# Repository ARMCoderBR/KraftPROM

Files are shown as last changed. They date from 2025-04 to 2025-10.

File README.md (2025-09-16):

## Project

EEPROM Programmer

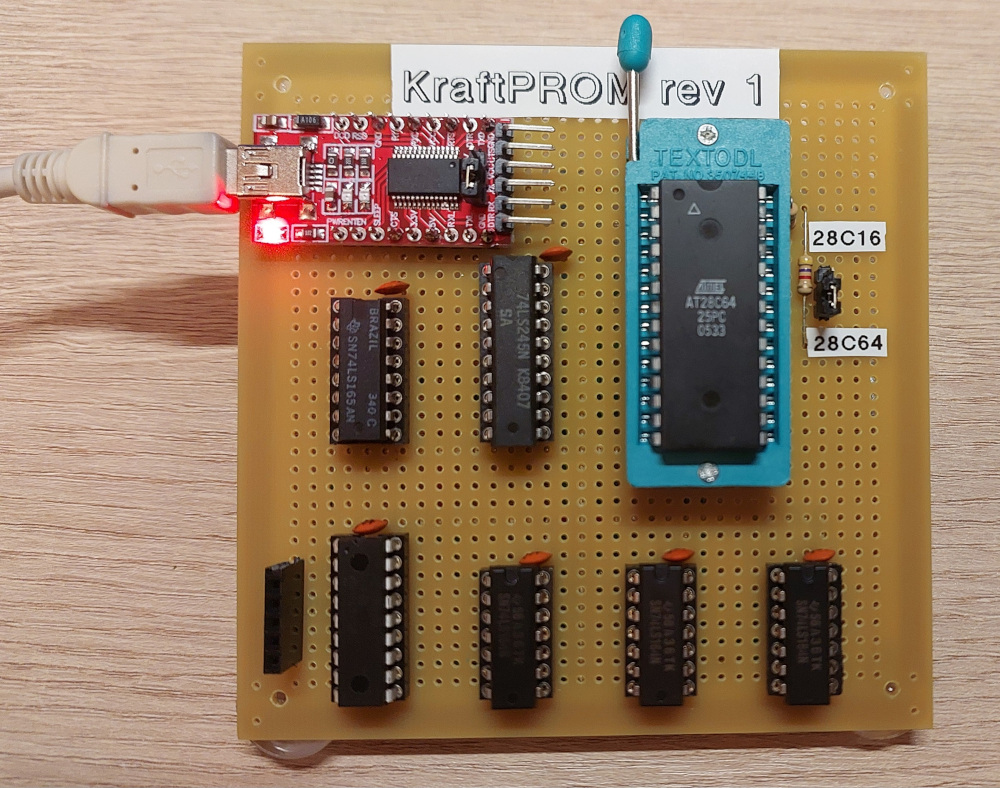
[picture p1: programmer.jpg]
EEPROM Programmer


## Description

A Hardware + Software suite to program EEPROMs (28C16 and 28C64).

## Version & Date
1.0 - 2025-APR-24

## Author
Milton Maldonado Jr (ARM_Coder)

## License
GPL V2

## Target

PC Client Software: Any Linux with GCC

The repo for the PC client is here: https://github.com/ARMCoderBR/eeprom_sender

Firmware: Microchip PIC16F628A under MPLABX IDE 6.X and XC8 2.X (no PRO License
          needed). A suitable HEX file is already supplied for this PIC, so no
          IDE and compiler will be needed unless you will choose to use a
          different PIC.

## Hardware Materials
```
1  x  Universal PCB or Breadboard
1  x  PIC16F628A
3  x  74LS164 or HC164
1  x  74LS245 or HC245
1  x  74LS165 or HC165
1  x  ZIF Socket DIP 28 PIN
7  x  Ceramic Cap 100nF
2  x  Resistor 4k7
1  x  Jumper 3 pin
1  x  Molex 5 pin female
3  x  DIP 14 Socket (not needed for breadboard)
1  x  DIP 16 Socket   "     "    "      "
1  x  DIP 18 Socket   "     "    "      "
1  x  DIP 20 Socket   "     "    "      "
1  x  PC Serial-to-TTL adapter with 5V compatibility
1+ x  28C16 or 28C64 as target(s)

Wires, solder, etc.
```

See picture and schematics.

NOTE: 

## Equipment needed to Build and Program

PC
USB cables
Solder
Cutter and pliers
Multimeter
PIC programmer dongle (eg Pickit3)

## Building the Programmer

As said, if you have the recommended PIC16F628A, you can program it with the
supplied HEX file. This is the easiest way because you don't need to install
the complete MPLABX and the C compiler.

**You will still need a PIC programming tool, that most likely you won't have.
Since programming this PIC is a once in a lifetime event, you'd better borrow
the programmer from a friend or use the company's programmer when no one is looking...**

The rest of the build is a no-brainer, just be careful with the connections.
The Serial-to-TTL adapter is very practical, it supplies the power to the
hardware (5VDC) and the communication signals (TX/RX/CTS).

## Using the Programmer

All the control is done by the PC client software, as indicated above.

## Disclaimer

This project is supplied 'as is' with no warranty against bugs and errors.

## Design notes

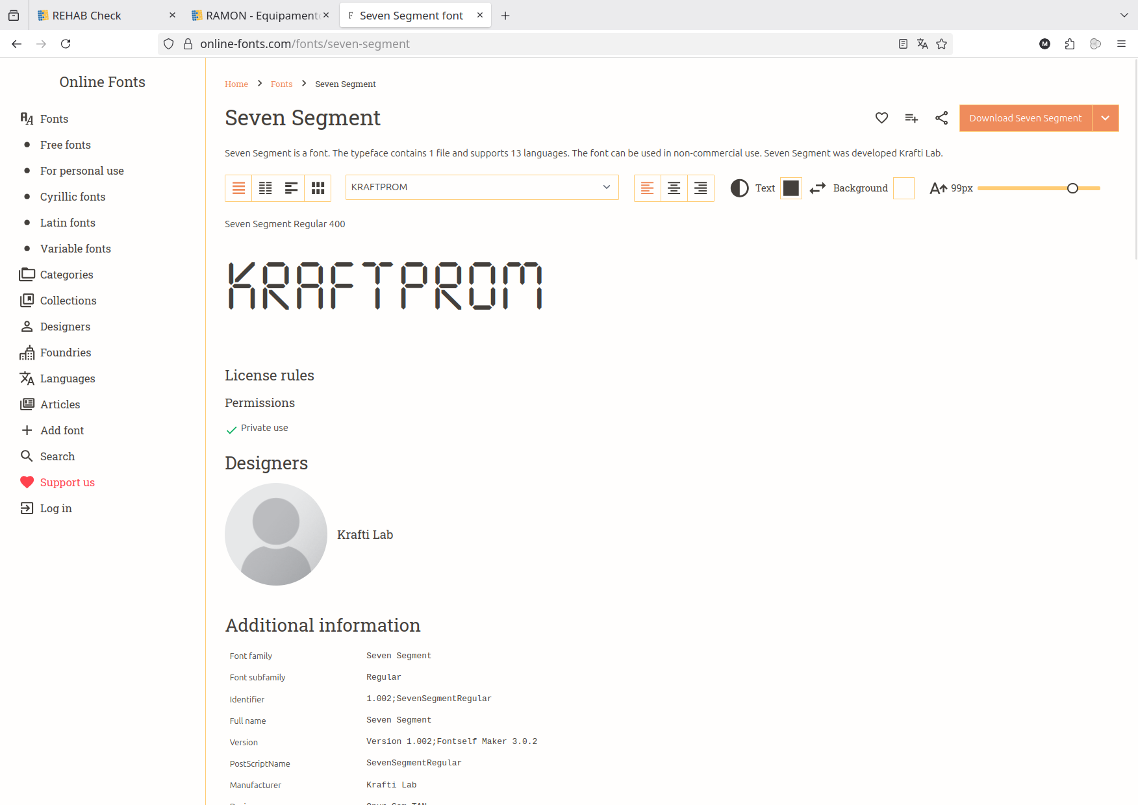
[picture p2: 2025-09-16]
Captura de tela_2025-09-16_14-19-43.png

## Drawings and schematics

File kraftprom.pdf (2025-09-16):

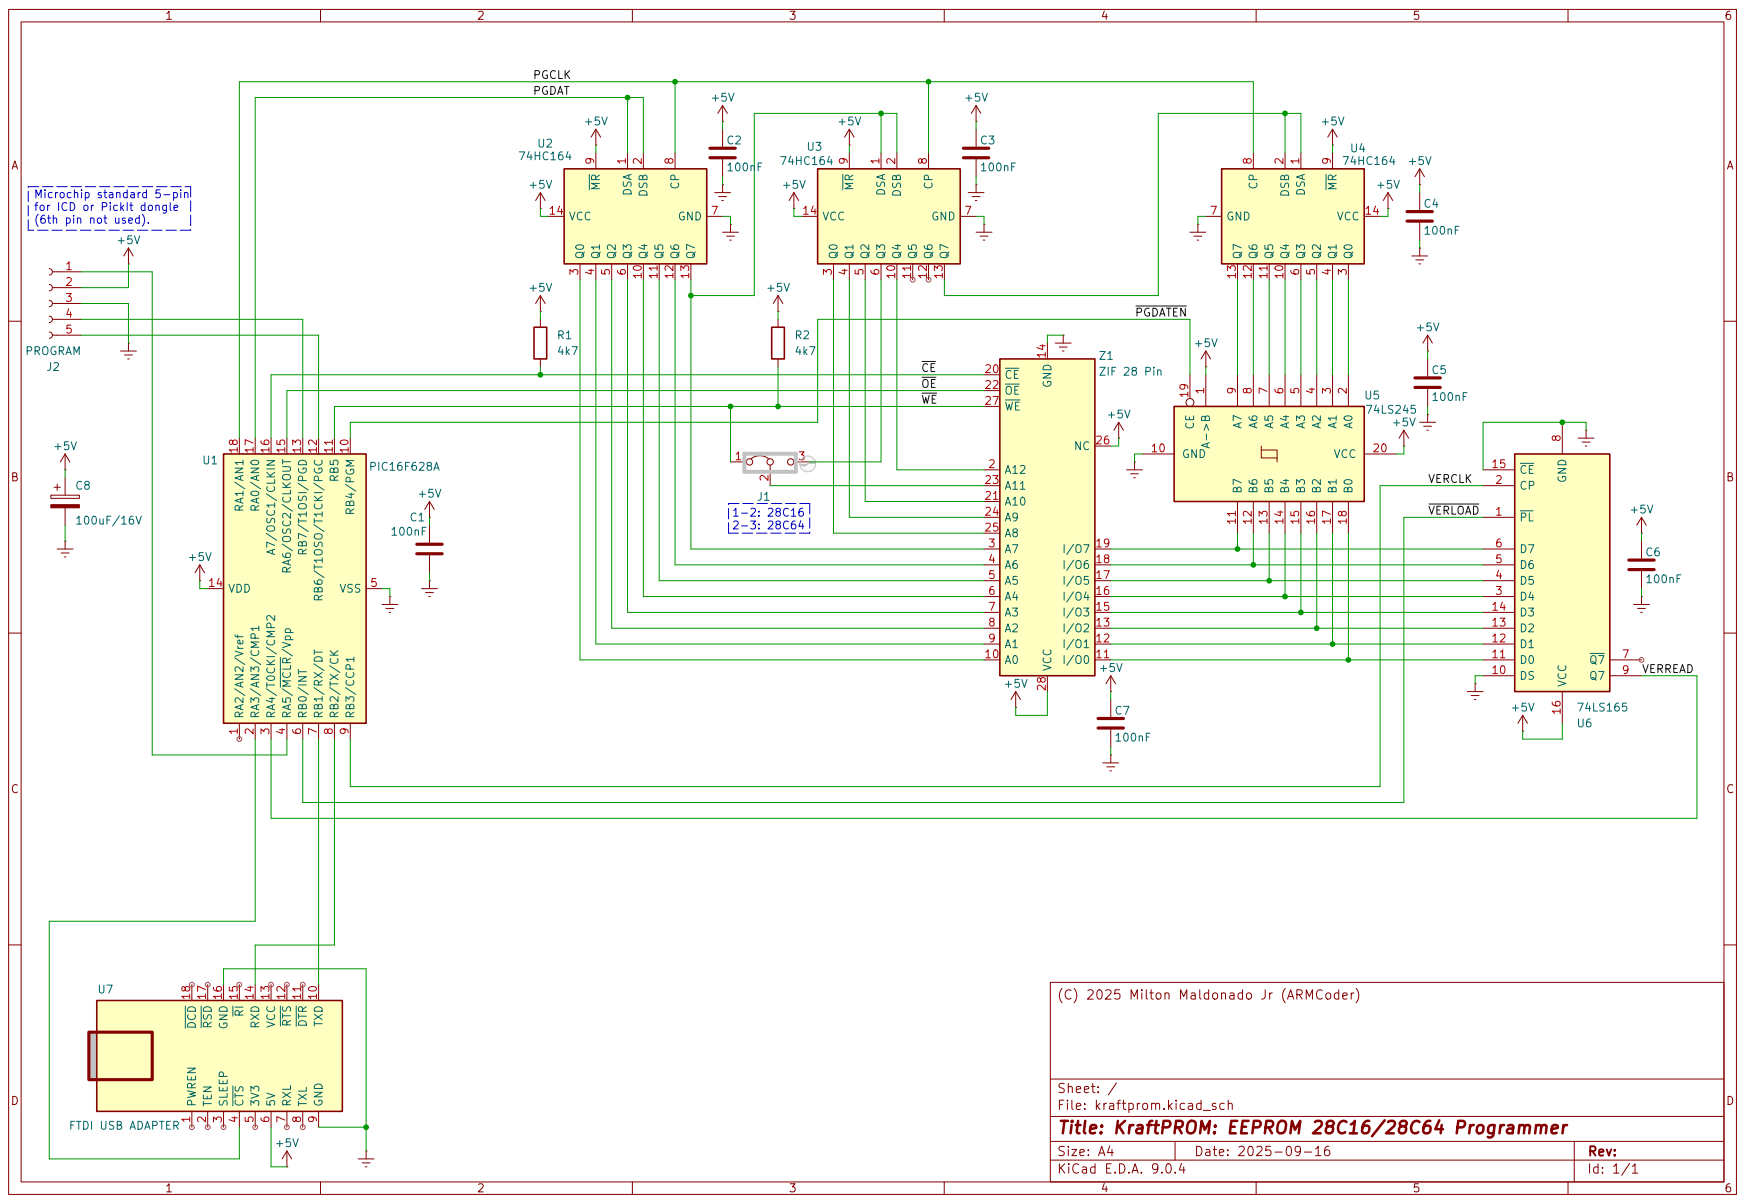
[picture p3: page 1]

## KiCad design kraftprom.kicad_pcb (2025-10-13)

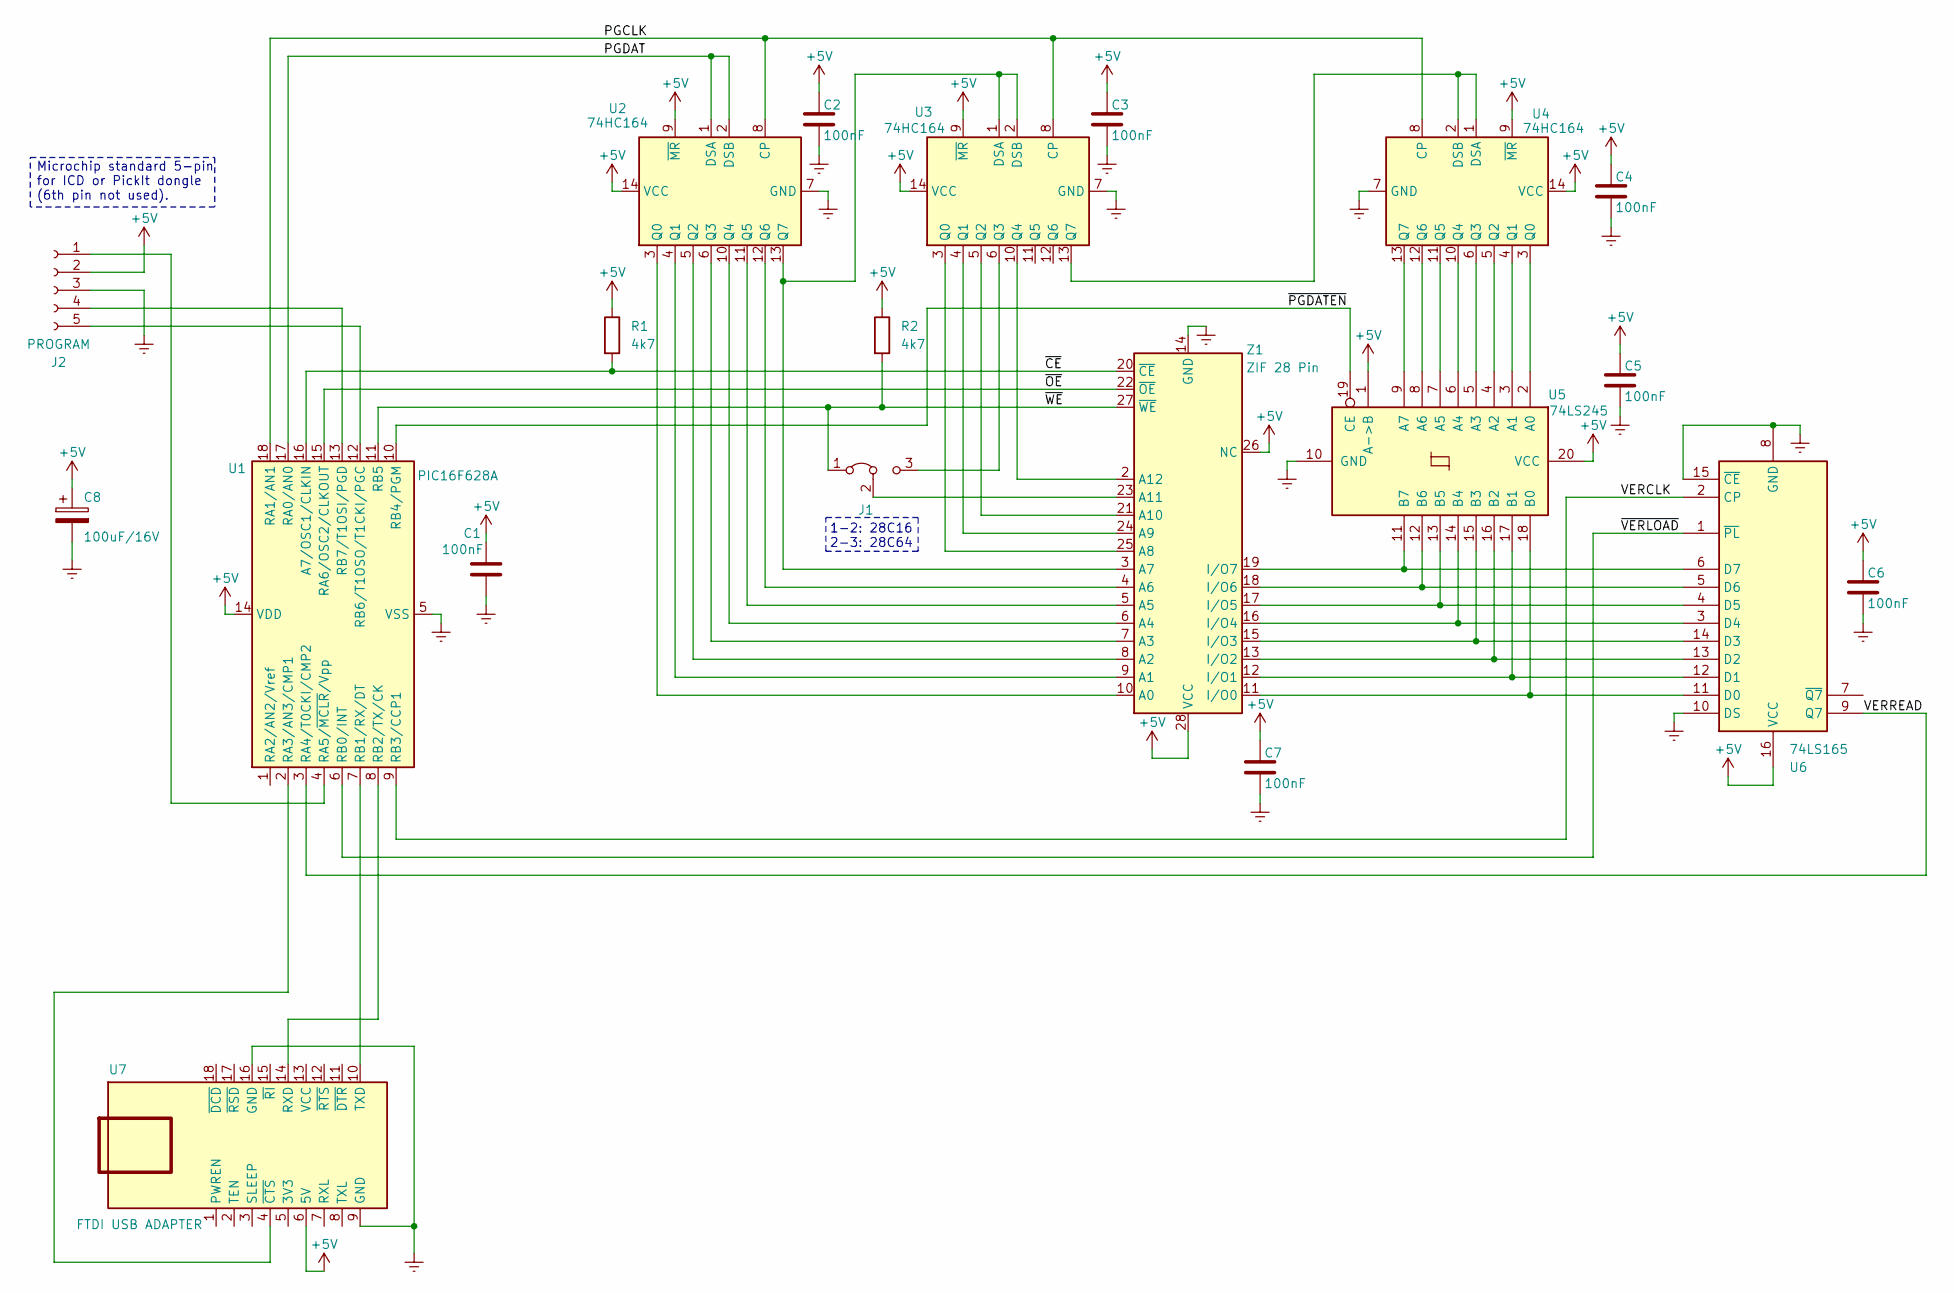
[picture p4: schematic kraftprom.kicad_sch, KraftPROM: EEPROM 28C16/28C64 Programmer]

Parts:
C1, C2, C3, C4, C5, C6, C7: 100nF
C8: 100uF/16V
J1: Jumper_3_Bridged12
J2: PROGRAM
R1, R2: 4k7
U1: PIC16F628A
U2, U3, U4: 74HC164
U5: 74LS245
U6: 74LS165
U7: FTDI USB ADAPTER
Z1: ZIF 28 Pin

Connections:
+5V: C1.1, C2.1, C3.1, C4.1, C5.1, C6.1, C7.1, C8.1, J2.2, R1.1, R2.1, U1.14 (VDD), U2.9 (~MR), U2.14 (VCC), U3.9 (~MR), U3.14 (VCC), U4.9 (~MR), U4.14 (VCC), U5.1 (A->B), U5.20 (VCC), U6.16 (VCC), U7.6 (5V), Z1.26 (NC), Z1.28 (VCC)
/PGCLK: U1.18 (RA1/AN1), U2.8 (CP), U3.8 (CP), U4.8 (CP)
/PGDAT: U1.17 (RA0/AN0), U2.1 (DSA), U2.2 (DSB)
/VERCLK: U1.9 (RB3/CCP1), U6.2 (CP)
/VERREAD: U1.3 (RA4/T0CKI/CMP2), U6.9 (Q7)
/~CE: R1.2, U1.16 (A7/OSC1/CLKIN), Z1.20 (~CE)
/~OE: U1.15 (RA6/OSC2/CLKOUT), Z1.22 (~OE)
/~PGDATEN: U1.10 (RB4/PGM), U5.19 (CE)
/~VERLOAD: U1.6 (RB0/INT), U6.1 (~PL)
/~WE: J1.1 (A), R2.2, U1.11 (RB5), Z1.27 (~WE)
Earth: C1.2, C2.2, C3.2, C4.2, C5.2, C6.2, C7.2, C8.2, J2.3, U1.5 (VSS), U2.7 (GND), U3.7 (GND), U4.7 (GND), U5.10 (GND), U6.8 (GND), U6.10 (DS), U6.15 (~CE), U7.9 (GND), U7.16 (GND), Z1.14 (GND)
unnamed: J1.3 (B), U3.6 (Q3)
unnamed: J1.2 (C), Z1.23 (A11)
unnamed: J2.1, U1.4 (RA5/~MCLR/Vpp)
unnamed: J2.4, U1.13 (RB7/T1OSI/PGD)
unnamed: J2.5, U1.12 (RB6/T1OSO/T1CKI/PGC)
unnamed: U1.2 (RA3/AN3/CMP1), U7.4 (~CTS)
unnamed: U1.7 (RB1/RX/DT), U7.10 (TXD)
unnamed: U1.8 (RB2/TX/CK), U7.14 (RXD)
unnamed: U2.3 (Q0), Z1.10 (A0)
unnamed: U2.4 (Q1), Z1.9 (A1)
unnamed: U2.5 (Q2), Z1.8 (A2)
unnamed: U2.6 (Q3), Z1.7 (A3)
unnamed: U2.10 (Q4), Z1.6 (A4)
unnamed: U2.11 (Q5), Z1.5 (A5)
unnamed: U2.12 (Q6), Z1.4 (A6)
unnamed: U2.13 (Q7), U3.1 (DSA), U3.2 (DSB), Z1.3 (A7)
unnamed: U3.3 (Q0), Z1.25 (A8)
unnamed: U3.4 (Q1), Z1.24 (A9)
unnamed: U3.5 (Q2), Z1.21 (A10)
unnamed: U3.10 (Q4), Z1.2 (A12)
unnamed: U3.13 (Q7), U4.1 (DSA), U4.2 (DSB)
unnamed: U4.3 (Q0), U5.2 (A0)
unnamed: U4.4 (Q1), U5.3 (A1)
unnamed: U4.5 (Q2), U5.4 (A2)
unnamed: U4.6 (Q3), U5.5 (A3)
unnamed: U4.10 (Q4), U5.6 (A4)
unnamed: U4.11 (Q5), U5.7 (A5)
unnamed: U4.12 (Q6), U5.8 (A6)
unnamed: U4.13 (Q7), U5.9 (A7)
unnamed: U5.18 (B0), U6.11 (D0), Z1.11 (I/O0)
unnamed: U5.17 (B1), U6.12 (D1), Z1.12 (I/O1)
unnamed: U5.16 (B2), U6.13 (D2), Z1.13 (I/O2)
unnamed: U5.15 (B3), U6.14 (D3), Z1.15 (I/O3)
unnamed: U5.14 (B4), U6.3 (D4), Z1.16 (I/O4)
unnamed: U5.13 (B5), U6.4 (D5), Z1.17 (I/O5)
unnamed: U5.12 (B6), U6.5 (D6), Z1.18 (I/O6)
unnamed: U5.11 (B7), U6.6 (D7), Z1.19 (I/O7)

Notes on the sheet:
1-2: 28C16 2-3: 28C64
Microchip standard 5-pin for ICD or PickIt dongle (6th pin not used).

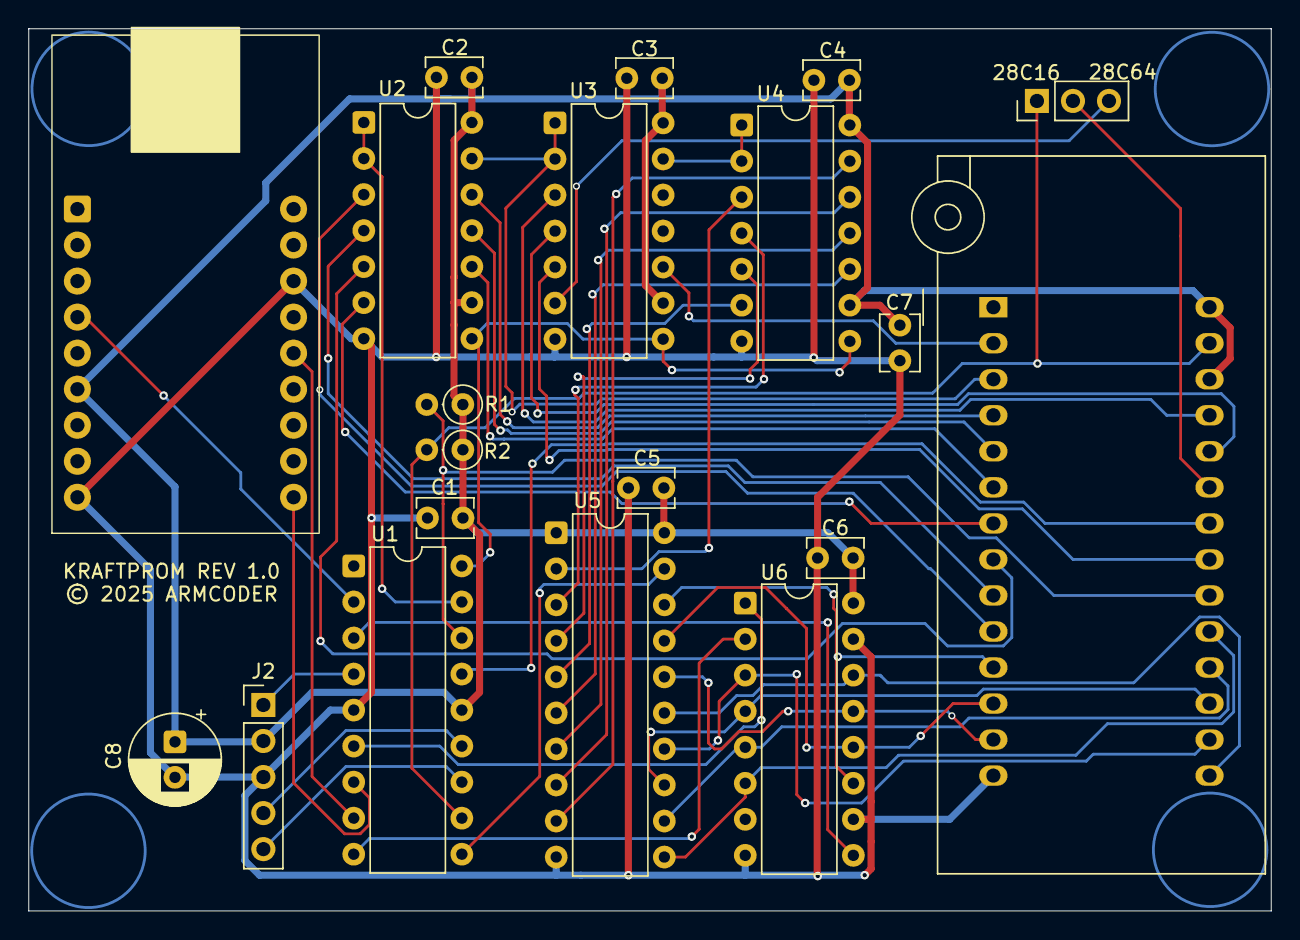
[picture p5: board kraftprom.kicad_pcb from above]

Board: 2 copper layers, 87.6 x 62.2 mm, 20 parts (0 on the bottom side), 48 nets.

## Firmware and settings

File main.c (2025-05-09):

/*
 * File:   main.c
 * Author: milton
 *
 * Created on 24 de Abril de 2025, 23:30
 */


#include <xc.h>
#include <pic.h>
#include <stdint.h>
#include "system.h"
#include "usart.h"

#define PGCLK_TRIS   TRISAbits.TRISA1
#define PGDAT_TRIS   TRISAbits.TRISA0
#define PGDATEN_TRIS TRISBbits.TRISB4
#define PGCLK        PORTAbits.RA1
#define PGDAT        PORTAbits.RA0
#define PGDATEN      PORTBbits.RB4

#define EECE_TRIS    TRISAbits.TRISA7
#define EEOE_TRIS    TRISAbits.TRISA6
#define EEWE_TRIS    TRISBbits.TRISB5
#define EECE         PORTAbits.RA7
#define EEOE         PORTAbits.RA6
#define EEWE         PORTBbits.RB5

#define VERCLK_TRIS  TRISBbits.TRISB3
#define VERLOAD_TRIS TRISBbits.TRISB0
#define VERREAD_TRIS TRISAbits.TRISA4
#define VERCLK       PORTBbits.RB3
#define VERLOAD      PORTBbits.RB0
#define VERREAD      PORTAbits.RA4


////////////////////////////////////////////////////////////////////////////////
void io_init(){
    
    PGCLK = 0;
    PGDAT = 0;
    PGCLK_TRIS = 0;
    PGDAT_TRIS = 0;
    PGDATEN = 1;
    PGDATEN_TRIS = 0;
    
    EECE = 1;
    EEOE = 1;
    EEWE = 1;
    EECE_TRIS = 0;
    EEOE_TRIS = 0;
    EEWE_TRIS = 0;

    VERCLK = 0;
    VERLOAD = 1;
    VERCLK_TRIS = 0;
    VERLOAD_TRIS = 0;
    VERREAD_TRIS = 1;
}

////////////////////////////////////////////////////////////////////////////////
void crlf(){
    
    USART_putcUSART(13);
    USART_putcUSART(10);
}

////////////////////////////////////////////////////////////////////////////////
void send_addr_data(uint16_t addr, uint8_t data){
    
    int i;

    for (i = 0; i < 8; i++){
        
        if (data & 0x80)
            PGDAT=1;
        else
            PGDAT=0;
        PGCLK=1;
        PGCLK=0;
        data <<= 1;
    }

    for (i = 0; i < 16; i++){
        
        if (addr & 0x8000)
            PGDAT=1;
        else
            PGDAT=0;
        PGCLK=1;
        PGCLK=0;
        addr <<= 1;
    }
}

////////////////////////////////////////////////////////////////////////////////
uint8_t read_ee_data(uint16_t addr){
    
    uint8_t val = 0;
    uint8_t msk = 0x80;
    
    send_addr_data(addr,0);
    //__delay_us(1);
    EECE = 0;
    EEOE = 0;
    __delay_us(1);
    VERLOAD = 0;
    VERLOAD = 1;
    EEOE = 1;
    EECE = 1;
    
    int i;
    for (i = 0; i < 8; i++){
        
        if (VERREAD)
            val |= msk;
        
        msk >>= 1;
        VERCLK = 1;
        VERCLK = 0;
        //__delay_us(1);
    }
    
    return val;
}

const char dighex[] = "0123456789ABCDEF";
////////////////////////////////////////////////////////////////////////////////
void print_hex8(uint8_t c){

    uint8_t ch = c >> 4;
    c &= 0x0f;
    
    USART_putcUSART(dighex[ch]);
    USART_putcUSART(dighex[c]);
}

////////////////////////////////////////////////////////////////////////////////
void dump_ee_data(uint16_t addr){

    print_hex8(addr >> 8);
    print_hex8(addr & 0xff);
    USART_putcUSART(':');
    
    print_hex8(read_ee_data(addr));
    crlf();
}

////////////////////////////////////////////////////////////////////////////////
#define POLLED 1
int write_ee_data(uint16_t addr, uint8_t data){
    
    send_addr_data(addr, data);

    PGDATEN = 0;
    __delay_us(1);
    EECE = 0;
    EEWE = 0;
    __delay_us(1);      // Pulse width Twp
    EEWE = 1;
    EECE = 1;
    __delay_us(1);      // Hold Tdh
    PGDATEN = 1;

#if POLLED
    __delay_us(1);
    EECE = 0;
    EEOE = 0;
    __delay_us(1);
    VERLOAD = 0;
    VERLOAD = 1;
    EEOE = 1;
    EECE = 1;
    data >>= 7;
    uint16_t timeout = 5000;
    //__delay_us(10);
    while (VERREAD != data){
        EECE = 0;
        EEOE = 0;
        __delay_us(1);
        VERLOAD = 0;
        VERLOAD = 1;
        EEOE = 1;
        EECE = 1;
        __delay_us(100);
        --timeout;
        if (!timeout) return -1;
    }
#else
    __delay_us(5000);   //Twc
#endif
    return 0;
}


////////////////////////////////////////////////////////////////////////////////
uint8_t getnibble(char c){

    if ((c >='0') && (c <= '9')) return c - '0';
    if ((c >='a') && (c <= 'f')) return c - 'a' + 10;
    if ((c >='A') && (c <= 'F')) return c - 'A' + 10;

    return 0;
}

////////////////////////////////////////////////////////////////////////////////
uint8_t bufprog[64];
uint8_t nbytes = 0;
uint8_t ctbytes = 0;
uint16_t paddr = 0;
uint8_t state = 0;
uint8_t type = 0;
uint8_t cksum = 0;
uint8_t cksum2 = 0;

void main(void) {
    
    USART_Initialize();

    INTCONbits.PEIE = 1;
    
    USART_putstr("EEPROM Programmer by Milton (ARMCoder)\r\n");
//    __delay_ms(1000);
//    USART_putstr("1\r\n");
//    __delay_ms(1000);
//    USART_putstr("2\r\n");

    ei();
    
    io_init();
    
    uint16_t i;

    read_ee_data(0);    // Força limpeza dos SHRs
    
    for (;;){
        
        if (usart_has_char()){
            
            uint8_t c = usart_getch();
            //USART_putcUSART(c);

            if ((c == 'x') /*&& (state >= 99)*/){
                state = 0;
                USART_putstr("\r\nReset\r\n");
            }
            
            if ((c == '?') && (state != 99)){
                USART_putstr("\r\nV1.00\r\n");
            }

            if ((c == ':') && (state != 99)){
                
                nbytes = 0; state = 0; paddr = 0; type = 0; ctbytes = 0; cksum = 0; cksum2 = 0; continue;
            }

            if ((c == '<') && (state != 99)){
                
                nbytes = 0; state = 20; paddr = 0; type = 0; ctbytes = 0; cksum = 0; cksum2 = 0; continue;
            }
            
            switch(state){
                
                ////////////////////////////////////////////////////////////////
                // Programming from INTEL HEX Line
                case 0:
                    nbytes = getnibble(c);
                    break;
                case 1:
                    nbytes <<= 4;
                    nbytes |= getnibble(c);
                    cksum2 += nbytes;
                    break;

                case 2:
                    paddr = getnibble(c);
                    break;
                case 3:
                    paddr <<= 4;
                    paddr |= getnibble(c);
                    cksum2 += paddr;
                    break;
                case 4:
                    paddr <<= 4;
                    paddr |= getnibble(c);
                    break;
                case 5:
                    paddr <<= 4;
                    paddr |= getnibble(c);
                    cksum2 += paddr;
                    break;
            
                case 6:
                    type |= getnibble(c);
                    break;
                case 7:
                    type <<= 4;
                    type |= getnibble(c);
                    cksum2 += type;
                    break;
            
                case 8:
                    bufprog[ctbytes] = getnibble(c);
                    break;
                case 9:
                    bufprog[ctbytes] <<=4;
                    bufprog[ctbytes] |= getnibble(c);
                    cksum2 += bufprog[ctbytes];
                    ctbytes++;
                    break;

                case 10:
                    cksum = getnibble(c);
                    break;
                case 11:
                    cksum <<=4;
                    cksum |= getnibble(c);
                    if (!((cksum + cksum2)&0xFF)){
                        USART_putstr("\r\nChecksum OK\r\n");
                        USART_putstr("ADDR:");
                        print_hex8(paddr>>8);
                        print_hex8(paddr);
                        USART_putstr("  BS:");
                        print_hex8(nbytes);
                        crlf();
                        for (i = 0; i < nbytes; i++){
                            if (write_ee_data(paddr+i,bufprog[i]) < 0){
                                USART_putstr("Timeout\r\n");
                                state = 99;
                                break;
                            };
                        }
                        for (i = 0; i < nbytes; i++){
                            if (read_ee_data(paddr+i) != bufprog[i]){//dump_ee_data(paddr+i);
                                USART_putstr("VERIFY ERROR\r\n"); 
                                state = 99;
                                break;
                            }
                        }
                        if (state != 99)
                            USART_putstr("Verify OK.\r\n"); 
                    }
                    else{
                        USART_putstr("\r\nHEX Checksum ERR:");
                        print_hex8(cksum);
                        print_hex8(cksum2);
                        crlf();
                        state = 99;
                    }
                    break;
            
                ////////////////////////////////////////////////////////////////
                // Reading and outputting INTEL HEX Line
                case 20:
                    paddr = getnibble(c);
                    break;
                case 21:
                    paddr <<= 4;
                    paddr |= getnibble(c);
                    cksum = paddr;
                    break;
                case 22:
                    paddr <<= 4;
                    paddr |= getnibble(c);
                    break;
                case 23:
                    paddr <<= 4;
                    paddr |= getnibble(c);
                    cksum += paddr;
                    break;
                case 24:
                    nbytes = getnibble(c);
                    break;
                case 25:
                    nbytes <<= 4;
                    nbytes |= getnibble(c);
                    cksum += nbytes;

                    USART_putcUSART(':');
                    print_hex8(nbytes);
                    print_hex8(paddr>>8);
                    print_hex8(paddr&0xFF);
                    USART_putcUSART('0');   // Type 0
                    USART_putcUSART('0');
                    
                    for (i = 0; i < nbytes; i++){
                        uint8_t c = read_ee_data(paddr+i);
                        print_hex8(c);
                        cksum += c;
                    }
                    print_hex8(1+(cksum^0xFF));
                    crlf();
                    break;
            }

            switch(state){

                case 7:
                    if (nbytes)
                        state++;
                    else
                        state = 10;
                case 9:
                    if (ctbytes < nbytes)
                        state = 8;
                    else
                        state = 10;
                    break;
                case 99:
                    USART_putstr("\r\nPress 'x' to restart process...\r\n");
                    state++;
                    break;
                default:
                    state++;
            }
            
            //__delay_us(100);
        }
    }


    return;
}

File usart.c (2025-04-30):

#include <xc.h>
#include <pic.h>
#include "usart.h"

#define USARTRXSIZE 32
char buf_usartrx[USARTRXSIZE];
uint8_t usart_head = 0;
uint8_t usart_tail = 0;
uint8_t usart_qty = 0;

/******************************************************************************
 * Function:        void USART_Initialize(void)
 *
 * PreCondition:    None
 *
 * Input:           None
 *
 * Output:          None
 *
 * Side Effects:    None
 *
 * Overview:        This routine initializes the UART to the value set by Host Terminal Application
 *
 * Note:
 *
 *****************************************************************************/

void USART_Initialize()
{
    unsigned char c;

    RTS = 0;
    RTS_TRIS = 0;

    di();

    usart_head = 0;
    usart_tail = 0;
    usart_qty = 0;
    //ANSELHbits.ANS11 = 0;    // Make RB5 pin digital
    RCSTAbits.SPEN = 1;
    UART_TRISRx=1;				// RX
    //ANSELCbits.ANSC7 = 0;       // Habilita input buffer.
    UART_TRISTx=0;				// TX
    TXSTA = 0x24;       	// TX enable BRGH=1
    RCSTA = 0x90;       	// Single Character RX

    int dwBaud = ((GetSystemClock()/16) / 19200) - 1;
    SPBRG = (uint8_t) dwBaud;
        
//        SPBRG = 0x71;
//        SPBRGH = 0x02;      	// 0x0271 for 48MHz -> 19200 baud
//    BAUDCON = 0x08;     	// BRG16 = 1
    c = RCREG;				// read
    PIE1bits.RCIE = 1;
//    IPR1bits.RCIP = 1;  // High prio.

    ei();

}//end USART_InitializeUSART

/******************************************************************************
 * Function:        void putcUSART(char c)
 *
 * PreCondition:    None
 *
 * Input:           char c - character to print to the UART
 *
 * Output:          None
 *
 * Side Effects:    None
 *
 * Overview:        Print the input character to the UART
 *
 * Note:
 *
 *****************************************************************************/
void USART_putcUSART(char c)
{
    TXREG = c;
    while(!TXSTAbits.TRMT);
}

/******************************************************************************
 * Function:        void USART_getcUSART(char c)
 *
 * PreCondition:    None
 *
 * Input:           None
 *
 * Output:          unsigned char c - character to received on the UART
 *
 * Side Effects:    None
 *
 * Overview:        Print the input character to the UART
 *
 * Note:
 *
 *****************************************************************************/
unsigned char __USART_getcUSART ()
{
	char  c;

	if (RCSTAbits.OERR)  // in case of overrun error
	{                    // we should never see an overrun error, but if we do,
		RCSTAbits.CREN = 0;  // reset the port
		c = RCREG;
		RCSTAbits.CREN = 1;  // and keep going.
	}
	else
    {
		c = RCREG;
    }
// not necessary.  EUSART auto clears the flag when RCREG is cleared
//	PIR1bits.RCIF = 0;    // clear Flag
  
	return c;
}

void USART_close(){
    
    PIE1bits.RCIE = 0;
    RCSTAbits.SPEN = 0;
    UART_TRISRx=1;				// RX
    //ANSELCbits.ANSC7 = 1;       // Desabilita input buffer.
    UART_TRISTx=1;				// TX
}

void usart_isr(void){
    
    if (usart_qty == USARTRXSIZE){
        __USART_getcUSART();
        return;
    }
    else
    if (usart_qty == (USARTRXSIZE - 8)){
        RTS = 1;
    }

    usart_qty++;
    buf_usartrx[usart_head++] = __USART_getcUSART();
    if (usart_head == USARTRXSIZE)
        usart_head = 0;
}

char usart_has_char(void){
    
    return usart_qty;
}

char usart_getch(void){
    
    if (!usart_qty){
        
        RTS = 0;
        return (0);
    }
    
    di();
    usart_qty--;
    char c = buf_usartrx[usart_tail++];
    ei();
    
    if (usart_tail == USARTRXSIZE)
        usart_tail = 0;
    return c;
}

void USART_putstr(char *s){
    
    while (*s)
        USART_putcUSART(*(s++));
}

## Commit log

2025-04-29 Shift registers de entrada funcinando.
2025-04-29 +Gravando a eeprom com parse de linhas INTEL Hex.
2025-07-10 Minor schematic and picture updates.
    [kraftprom.kicad_sch]
2025-09-16 More PCB design.
    [kraftprom.kicad_pcb]
2025-09-16 More PCB design (fixes).
    [kraftprom.kicad_pcb, kraftprom.kicad_sch]
2025-09-17 More PCB design (clearances).
    [kraftprom.kicad_pcb]
2025-10-13 More PCB fixes.
    [kraftprom.kicad_pcb, kraftpromRev2.kicad_pcb]

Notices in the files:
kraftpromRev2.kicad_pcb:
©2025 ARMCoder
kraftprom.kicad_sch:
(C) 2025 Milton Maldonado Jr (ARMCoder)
